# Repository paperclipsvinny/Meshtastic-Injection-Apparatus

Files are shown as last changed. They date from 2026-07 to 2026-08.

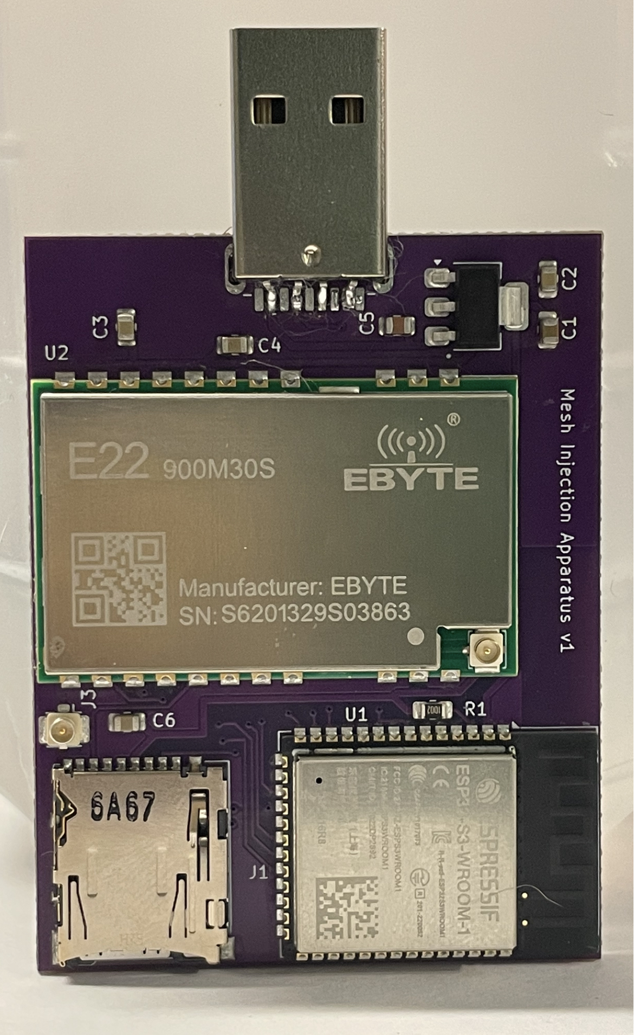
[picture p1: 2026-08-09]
website/assets/MIA-PCB-Front.jpg

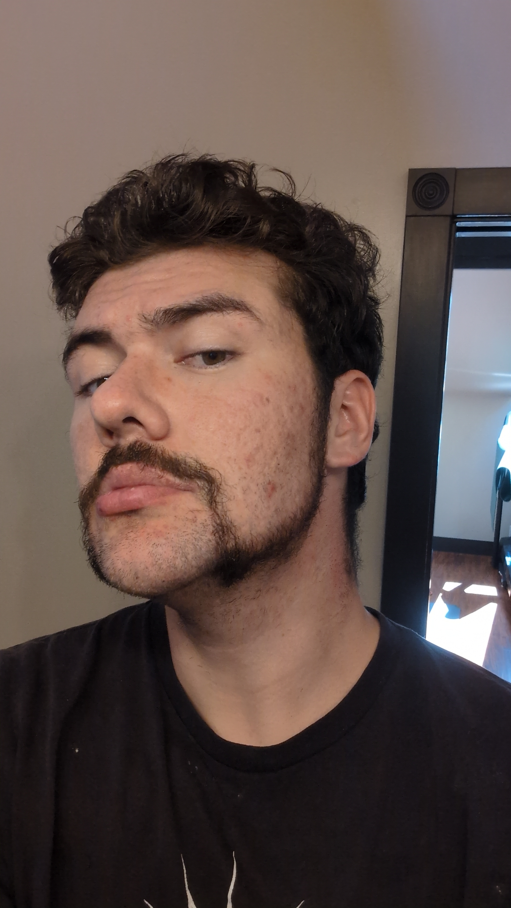
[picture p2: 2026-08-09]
photo1.jpg

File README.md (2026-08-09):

# Mesh Injection Apparatus (M.I.A.) 
A tool that combines HID injection with LoRa (Meshtastic) mesh networking for a red team implant that doesn't rely on WiFi or internet for C2. 
Board both sides

## DISCLAIMER: 
**This is a covert keystroke injection tool, designed for Red Teams, Penetration Testers, and authorized testing only. Do NOT use this tool on any systems which you have not been given express, explicit permission. I, the author, am not responsible for any damages which may incur from using this tool.** 

## Where is everything?
For Firmware Architecture notes, check out [ARCHITECTURE.md](./ARCHITECTURE.md). 
Hardware, Schematics and PCB manufacturing files can be found under [`/Hardware`](./Hardware) . 

For technical Documentation, head over to [DOCUMENTATION.md](docs/DOCUMENTATION.md), also available at [TheMIA.dev](https://themia.dev)

As debuted at the [DEF CON 34 Main stage](https://defcon.org/html/defcon-34/dc-34-speakers.html#content_66655)

## LICENSE: 
This project is released under the **MIT license**. 
 Anyone is permitted to modify, distribute, and use anything from this project for both private and commercial use. 
### Conditions: 
You must provide a copy of the original copyright notice and include the full MIT license text, found in LICENSE.txt. 
### Limitations: 
The software is NOT under any warranty, and the author will not be held responsible for any damages or issues arising from this software. The original Author’s name and original logos cannot be used for marketing or promotion. 

## Credits & Inspiration
- **[Meshtastic](https://meshtastic.org)** — the mesh protocol MIA builds on
- **[RadioLib](https://github.com/jgromes/RadioLib)** — LoRa radio abstraction
- **[Loki](https://github.com/RocketGod-git/Meshtastic-Loki)** — Meshtastic fork that added HID 
  support, the direct inspiration for MIA's development. 
- **[EvilCrowRF](https://github.com/joelsernamoreno/EvilCrowRF-V2)** — web dashboard 
  design inspiration.

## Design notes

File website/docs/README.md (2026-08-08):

# MIA Documentation

**M.esh I.njection A.pparatus** — wireless HID injection over encrypted LoRa mesh.

---

## Where to start

New here? Start with [Getting Started → Quickstart](getting-started/quickstart.md).

Already flashed? Jump to [Serial API](firmware/serial-api.md) or the [Web API](firmware/web-api.md).

Building hardware? See [Hardware Overview](hardware/overview.md).

---

## Contents

### Getting Started
- [Requirements](getting-started/requirements.md) — what you need before you begin
- [Flashing](getting-started/flashing.md) — web flasher + PlatformIO fallback
- [Quickstart](getting-started/quickstart.md) — fastest path to first injection

### Hardware
- [Overview](hardware/overview.md) — supported boards, pinouts
- [Bill of Materials](hardware/bill-of-materials.md) — what's on the MIA PCB
- [Heltec V3](hardware/heltec-v3.md) — reference platform notes
- [MIA PCB](hardware/mia-pcb.md) — custom board details

### Firmware
- [Architecture](firmware/architecture.md) — how the firmware is structured
- [Building](firmware/build.md) — PlatformIO setup and environments
- [Serial API](firmware/serial-api.md) — USB serial command reference
- [Web API](firmware/web-api.md) — HTTP endpoint reference
- [Payloads](firmware/payloads.md) — DuckyScript syntax and examples

### Meshtastic Integration
- [Overview](meshtastic-integration/overview.md) — how MIA fits into the mesh
- [Links](meshtastic-integration/links.md) — official Meshtastic resources

### Security
- [Considerations](security/considerations.md) — PSK handling, responsible use

### Contributing
- [Setup](contributing/setup.md) — dev environment
- [Code Style](contributing/code-style.md)
- [Changelog](contributing/changelog.md)

### [FAQ](faq.md)

---

Full docs are also available at **[themia.dev](https://themia.dev)**.

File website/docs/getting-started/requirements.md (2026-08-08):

# Requirements

## Hardware

You need one of these:

| Board | Notes |
|---|---|
| **Heltec WiFi LoRa 32 V3** | Reference platform. Tested and confirmed working. Has built-in display (unused by MIA), OLED, USB-C. |
| **MIA PCB v1** | Custom ESP32-S3 + E22-900M30S board. v2 in development. |

Any ESP32-S3 board with an SX1262-compatible LoRa module should work with minor pin changes — see [Building](../firmware/building.md).

You also need:
- A **USB data cable** (not charge-only — MIA enumerates as a USB keyboard)
- A **Meshtastic node** to send commands from — any standard device works (phone app, stock Heltec, T-Beam, etc.)
- An **antenna** for the LoRa module (900 MHz for US, 868 MHz for EU)

## Software

| Tool | Required for |
|---|---|
| Chrome or Edge | Web flasher at themia.dev |
| Python 3 + pyserial | Serial CLI (`tools/mia-cli.py`) |
| PlatformIO | Building from source |
| Meshtastic app | Sending commands over the mesh |

## OS support

MIA has been tested on **Linux** (Fedora, Ubuntu). It should work on macOS and Windows with the standard PlatformIO toolchain — serial port naming will differ (`/dev/cu.usbmodem*` on macOS, `COM*` on Windows).

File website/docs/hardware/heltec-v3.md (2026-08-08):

# Heltec WiFi LoRa 32 V3

The reference platform for MIA development. If you're just getting started, use this board.

## Specs

- **MCU:** ESP32-S3, 240MHz dual-core
- **Flash:** 8MB
- **LoRa:** SX1262, up to 22dBm TX power
- **USB:** Native USB-C (no separate UART bridge chip)
- **Display:** 0.96" OLED (unused by MIA firmware)
- **Buttons:** BOOT + RESET (makes flashing easy)

## Notes

- The Heltec V3 has a TCXO (temperature-compensated crystal oscillator) on the LoRa module at 1.8V — this is why `LORA_TXCOVOLT 1.8` is set in `Radio.h`. Don't remove this or the radio won't initialize.
- Native USB means the board enumerates as `/dev/ttyACM0` (not `/dev/ttyUSB0`) on Linux when using USB CDC mode. The `platformio.ini` `upload_port` should match whichever your system assigns.
- `ARDUINO_USB_CDC_ON_BOOT=0` is set for this board — serial output is available but the CDC interface doesn't start until after `Serial.begin()` in setup.
- `VEXT_ENABLE` (GPIO36, active LOW) controls power to peripherals including the display. MIA pulls this LOW on boot to enable the LoRa module's power path.

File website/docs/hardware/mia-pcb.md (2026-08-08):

# MIA PCB v1

A custom USB-A form-factor board designed to plug directly into a target machine and disappear — it looks like a USB drive.

## Design goals

- USB-A plug built into the PCB edge (gold-plated contacts) — plugs directly into any USB-A port
- ESP32-S3-WROOM-1 (N16R8) for processing and native USB HID
- E22-900M30S for long-range LoRa comms
- MicroSD slot for payload storage
- Compact enough to leave in a machine without drawing attention

## Current status

**v1 has a hardware bug** — A routing error on v1 boards prevents the E22 LoRa module from
initializing. v2 corrects the routing error and adds BOOT/RESET buttons + an LED.

## Pin mapping

| Signal | ESP32 GPIO |
|---|---|
| LORA_CS (NSS) | 8 |
| LORA_RST | 12 |
| LORA_BUSY | 13 |
| LORA_DIO1 | 14 |
| LORA_SCK | 9 |
| LORA_MOSI | 10 |
| LORA_MISO | 11 |
| SD_CS | 4 |
| SD_DETECT | 5 (optional) |
| USB_D- | 19 (native) |
| USB_D+ | 20 (native) |

## Flashing v1 boards

v1 has no BOOT/RESET buttons. To enter bootloader mode:
1. Bridge GPIO0 (physical pad 10 on the WROOM-1) to GND while powering on
2. Release after the board enumerates
3. Run `pio run -e mia_pcb -t upload`

Native USB auto-reset works once firmware is installed.

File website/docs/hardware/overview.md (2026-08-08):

# Hardware Overview

MIA firmware runs on ESP32-S3-based LoRa boards. The reference platform is the **Heltec WiFi LoRa 32 V3**.

## Supported boards

| Board | LoRa Module | Status |
|---|---|---|
| Heltec WiFi LoRa 32 V3 | SX1262 | ✅ Tested |
| MIA PCB v1 | E22-900M30S (SX1262-compatible) | 🔧 v2 in development |

## Pin mapping (Heltec V3 / MIA PCB v1)

| Signal | GPIO |
|---|---|
| LORA_CS | 8 |
| LORA_DIO1 | 14 |
| LORA_RST | 12 |
| LORA_BUSY | 13 |
| LORA_MISO | 11 |
| LORA_MOSI | 10 |
| LORA_SCK | 9 |

These are defined in `Radio.h` and can be changed per board via `#ifdef` guards in `platformio.ini`.

## Adding a new board

1. Add a new `[env:your_board]` in `platformio.ini`
2. Add `-DYOUR_BOARD` to `build_flags`
3. Add an `#ifdef YOUR_BOARD` pin block in `Radio.h`
4. Add `#ifndef YOUR_BOARD` guards around any board-specific peripherals in `main.cpp` (LED, VEXT, etc.)

See [Building](../firmware/building.md) for the full environment setup.

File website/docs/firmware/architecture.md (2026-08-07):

# Firmware Architecture

The firmware is divided into independent subsystems, each owning a single concern.

## Radio
- SPI/LoRa hardware initialization via RadioLib (SX1262/E22)
- Runtime-configurable parameters: frequency, bandwidth, spread factor, coding rate, TX power
- RX interrupt handling and packet reception
- Signal reporting: RSSI, SNR, IRQ flags
- NVS-backed persistence — settings survive reboot
- Getters/setters exposed to SerialApi and WebApi

## Crypto
- AES-CTR decryption using ESP32 hardware AES (mbedTLS)
- Supports AES-128 (16-byte) and AES-256 (32-byte) PSKs
- Per-packet nonce construction from packet ID + source address (Meshtastic CTR scheme)
- Runtime PSK update via setKey() — no reflash required
- NVS-backed persistence for active PSK

## PacketParser
- Parses the 14-byte Meshtastic packet header (dest, source, packetId, flags, channel)
- Extracts text messages from decrypted protobuf payloads (text app message format)
- Deduplication handled in main.cpp via packetId + source tracking

## HID
- DuckyScript command parsing and execution
- USB HID keyboard initialization and keystroke injection
- Handles modifier keys (CTRL, ALT, SHIFT, GUI) with press/release pairs
- Retransmission deduplication prevents duplicate command execution

## Logger
- Centralized serial output (raw, info, formatted, hex byte)
- Replaces all direct Serial.print calls throughout the firmware

## StatusLED
- Visual feedback via onboard LED
- 3x fast blink pattern on packet received
- Conditionally compiled out on boards with no LED (MIA_PCB)

## SerialApi
- JSON-over-serial command interface (115200 baud, newline-terminated)
- Commands: get_config, set_config, get_psk, set_psk, get_wifi, set_wifi,
  save_defaults, reset_defaults
- All changes applied live and persisted to NVS immediately

## WebApi
- HTTP server over ESP32 WiFi AP (ESPAsyncWebServer)
- Mirrors SerialApi's command surface over REST endpoints
- Serves web dashboard (index.html) from LittleFS
- WPA2-secured AP; POST endpoints require Content-Type: application/json

## WifiConfig
- Holds AP SSID, password, and enabled state
- NVS-backed persistence via Preferences
- Read/written by both SerialApi (set_wifi) and WebApi

## Multi-board support
Firmware supports multiple hardware targets via PlatformIO environments:
- `heltec_wifi_lora_32_V3` — Heltec WiFi LoRa 32 V3 (reference/tested platform)
- `mia_pcb` — MIA v1 custom PCB (ESP32-S3-WROOM-1 + E22-900M30S, pending hardware fix)

Board-specific differences (LED, VEXT_ENABLE) are handled via `#ifdef MIA_PCB` guards.

## Tools
- `tools/mia-cli.py` — interactive serial CLI (Python, `cmd` module)
  Commands: get/set/gen/defaults/monitor
  Connects over USB serial, no firmware changes required

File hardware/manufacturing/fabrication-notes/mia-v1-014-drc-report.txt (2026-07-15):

** Drc report for Mesh_Injection_Apparatus_v1_014.kicad_pcb **
** Created on 2026-07-10T18:35:10 **
** Report includes: Errors, Warnings **

** Found 7 DRC violations **
[copper_edge_clearance]: Board edge clearance violation (board setup constraints edge clearance 0.5000 mm; actual 0.0500 mm)
    Rule: board setup constraints edge; error
    @(137.5000 mm, 74.0000 mm): Polygon on Edge.Cuts
    @(156.0500 mm, 71.1500 mm): Pad 1 [+5V] of REF** on F.Cu
[copper_edge_clearance]: Board edge clearance violation (board setup constraints edge clearance 0.5000 mm; actual 0.1500 mm)
    Rule: board setup constraints edge; error
    @(137.5000 mm, 74.0000 mm): Polygon on Edge.Cuts
    @(158.5000 mm, 71.1500 mm): Pad 2 [Net-(J2-D-)] of REF** on F.Cu
[copper_edge_clearance]: Board edge clearance violation (board setup constraints edge clearance 0.5000 mm; actual 0.1500 mm)
    Rule: board setup constraints edge; error
    @(137.5000 mm, 74.0000 mm): Polygon on Edge.Cuts
    @(161.0000 mm, 71.1500 mm): Pad 3 [Net-(J2-D+)] of REF** on F.Cu
[copper_edge_clearance]: Board edge clearance violation (board setup constraints edge clearance 0.5000 mm; actual 0.1500 mm)
    Rule: board setup constraints edge; error
    @(137.5000 mm, 74.0000 mm): Polygon on Edge.Cuts
    @(163.5000 mm, 71.1500 mm): Pad 4 [GND] of REF** on F.Cu
[track_dangling]: Track has unconnected end
    Local override; warning
    @(150.7800 mm, 86.0000 mm): Track [Net-(U2-DIO2)] on B.Cu, length 2.5400 mm
[lib_footprint_issues]: The current configuration does not include the footprint library 'E22-900M30S'
    Local override; warning
    @(157.2600 mm, 97.5750 mm): Footprint U2
[lib_footprint_mismatch]: Footprint 'ESP32-S3-WROOM-1' does not match copy in library 'RF_Module'
    Local override; warning
    @(170.1487 mm, 123.2868 mm): Footprint U1

** Found 2 unconnected pads **
[unconnected_items]: Missing connection between items
    Local override; error
    @(148.2400 mm, 86.0000 mm): Pad 8 [Net-(U2-DIO2)] of U2 on F.Cu
    @(150.7800 mm, 86.0000 mm): Track [Net-(U2-DIO2)] on B.Cu, length 2.5400 mm
[unconnected_items]: Missing connection between items
    Local override; error
    @(150.7800 mm, 86.0000 mm): Track [Net-(U2-DIO2)] on B.Cu, length 2.5400 mm
    @(150.7800 mm, 86.0000 mm): Pad 7 [Net-(U2-DIO2)] of U2 on F.Cu

** Found 0 Footprint errors **

** Ignored checks **
    - Footprint has no courtyard defined
    - Track endpoint not centered on via
    - Tuning profile track geometries
    - Footprint doesn't match symbol's footprint filters
    - Footprint component type doesn't match footprint pads

** End of Report **

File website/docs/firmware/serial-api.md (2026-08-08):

# Serial API Reference

MIA accepts JSON commands over USB serial at **115,200 baud**. Each command is a single line of JSON terminated with a newline (`\n`).

The easiest way to interact with the serial API is the included CLI tool:

```bash
python3 tools/mia-cli.py /dev/ttyUSB0
```

Or raw serial (useful for scripting):

```bash
python3 -c "
import serial, time
s = serial.Serial('/dev/ttyUSB0', 115200, timeout=2)
time.sleep(5)          # wait for boot
s.reset_input_buffer()
s.write(b'{\"cmd\":\"get_config\"}\n')
time.sleep(0.5)
print(s.read(s.in_waiting or 1).decode())
"
```

> **Note:** Wait a few seconds after opening the port for the device to finish booting before sending commands. Sending too early can mix your command with boot output and cause a parse error.

---

## Radio configuration

### `get_config`

Returns current radio parameters.

**Request:**
```json
{"cmd": "get_config"}
```

**Response:**
```json
{
  "frequency": 906.875,
  "bandwidth": 250,
  "spreadFactor": 11,
  "codingRate": 5,
  "power": 22
}
```

---

### `set_config`

Updates one or more radio parameters. Only include the fields you want to change. Changes take effect immediately and persist across reboots.
- `frequency`: frequency in MHz (e.g. 906.875)
- `bandwidth`: bandwidth in kHz (e.g. 250.0)  
- `codingRate`: coding rate (5–8)
Example:
**Request:**
```json
{"cmd": "set_config", "spreadFactor": 9, "power": 17}
```

**Response:**
```json
{"status": "ok"}
```

**Valid ranges:**
- `spreadFactor`: 7–12 (RadioLib validates this; invalid values return `{"status":"error"}`)
- `power`: −9 to 22 dBm

---

## PSK (channel key)

### `get_psk`

Returns the current AES channel key as base64.

**Request:**
```json
{"cmd": "get_psk"}
```

**Response:**
```json
{"psk": "1PG7OiApB1nwvP+rz05pAQ=="}
```

The response includes the raw base64 key. Decode it to get the actual bytes: 24 characters = 16 bytes (AES-128), 44 characters = 32 bytes (AES-256).

---

### `set_psk`

Sets a new AES channel key. Must be a valid base64 string that decodes to exactly 16 bytes (AES-128) or 32 bytes (AES-256).

**Request:**
```json
{"cmd": "set_psk", "psk": "uUAKMhSSaaZpRNM0ytp6qw=="}
```

**Response:**
```json
{"status": "ok"}
```

To match a Meshtastic private channel, find the PSK in the Meshtastic app's channel settings (shown as base64) and pass it directly here.

---

## WiFi / AP settings

### `get_wifi`

Returns current WiFi AP configuration. The password is intentionally omitted from the response.

**Request:**
```json
{"cmd": "get_wifi"}
```

**Response:**
```json
{"enabled": true, "ssid": "Mesh Injection Apparatus"}
```

---

### `set_wifi`

Updates WiFi AP settings. Any combination of fields can be included. SSID and password changes require a reboot to take effect; the `enabled` toggle applies on the next boot.

**Request:**
```json
{"cmd": "set_wifi", "ssid": "MyMIA", "password": "newpassword", "enabled": true}
```

**Response:**
```json
{"status": "ok"}
```

---

## Defaults

### `save_defaults`

Saves the current configuration (radio, PSK, WiFi) as a named restore point. A subsequent `reset_defaults` will return to these values rather than the compiled-in factory values.

**Request:**
```json
{"cmd": "save_defaults"}
```

**Response:**
```json
{"status": "ok", "msg": "current config saved as defaults"}
```

---

### `reset_defaults`

Restores previously saved defaults. If no defaults have been saved, wipes NVS entirely and reverts to compiled-in factory values on next reboot.

**Request:**
```json
{"cmd": "reset_defaults"}
```

**Response:**
```json
{"status": "ok", "msg": "defaults restored, reboot to apply"}
```

or, if no saved defaults exist:

```json
{"status": "ok", "msg": "factory reset, reboot to apply"}
```

---

## Error responses

All commands return a consistent error format for invalid input:

| Response | Meaning |
|---|---|
| `{"error":"invalid json"}` | The line sent wasn't valid JSON |
| `{"error":"unknown cmd"}` | The `cmd` field wasn't recognized |
| `{"error":"psk must decode to 16 or 32 bytes"}` | The PSK base64 string decoded to an invalid length |
| `{"status":"error"}` | The radio rejected a parameter (e.g. out-of-range spread factor) |

---

## Serial CLI quick reference

```
mia> get config              read radio parameters
mia> get psk                 read current PSK
mia> get wifi                read AP settings
mia> get status              read everything at once

mia> set sf <7-12>           set spread factor
mia> set power <dBm>         set TX power
mia> set psk <base64>        set channel key
mia> set ssid <name>         set AP network name
mia> set password <pass>     set AP password
mia> set wifi <on|off>       enable or disable the AP

mia> set freq <MHz>          set frequency
mia> set bw <kHz>            set bandwidth  
mia> set cr <5-8>            set coding rate

mia> gen psk 128             generate and apply a random 128-bit key
mia> gen psk 256             generate and apply a random 256-bit key

mia> defaults save           save current config as restore point
mia> defaults reset          restore saved defaults (or factory reset)

mia> monitor                 stream live serial output
mia> exit                    disconnect
```

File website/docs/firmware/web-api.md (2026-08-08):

# Web API Reference

MIA exposes an HTTP REST API served over its own WiFi AP. All endpoints are available at `http://192.168.4.1` when connected to the MIA AP.

> **Important:** POST endpoints require the header `Content-Type: application/json`. Omitting this header causes ESPAsyncWebServer to skip the request body, resulting in a silent empty response.

---

## Radio configuration

### `GET /api/config`

Returns current radio parameters.

**Response:**
```json
{
  "frequency": 906.875,
  "bandwidth": 250,
  "spreadFactor": 11,
  "codingRate": 5,
  "power": 22
}
```

---

### `POST /api/config`

Updates radio parameters. Only include fields you want to change.

**Request:**
```json
{"spreadFactor": 9, "power": 17}
```

**Response:**
```json
{"status": "ok"}
```

**Example:**
```bash
curl -X POST http://192.168.4.1/api/config \
  -H "Content-Type: application/json" \
  -d '{"spreadFactor": 9}'
```

---

## PSK (channel key)

### `GET /api/psk`

Returns the current AES key as base64.

**Response:**
```json
{"psk": "1PG7OiApB1nwvP+rz05pAQ=="}
```

---

### `POST /api/psk`

Sets a new AES channel key.

**Request:**
```json
{"psk": "uUAKMhSSaaZpRNM0ytp6qw=="}
```

Must decode to exactly 16 bytes (AES-128) or 32 bytes (AES-256).

---

## WiFi / AP settings

### `GET /api/wifi`

Returns current AP configuration. Password is omitted.

**Response:**
```json
{"enabled": true, "ssid": "Mesh Injection Apparatus"}
```

---

### `POST /api/wifi`

Updates AP settings. Include any combination of fields.

**Request:**
```json
{"enabled": true, "ssid": "MyMIA", "password": "newpassword"}
```

SSID and password take effect after reboot.

---

## Inject

### `POST /api/inject/fire`

Executes a DuckyScript command locally via USB HID. The MIA device must be plugged into a target machine.

**Request:**
```json
{"command": "STRINGLN hello world"}
```

The `!mia:` prefix is stripped automatically if present.

**Response:**
```json
{"status": "ok"}
```

**Example:**
```bash
curl -X POST http://192.168.4.1/api/inject/fire \
  -H "Content-Type: application/json" \
  -d '{"command": "GUI r, DELAY 500, STRINGLN notepad, ENTER"}'
```

---

### `POST /api/inject/transmit`

Transmits a `!mia:` prefixed command over LoRa to other MIA devices on the same channel.

**Request:**
```json
{"command": "STRINGLN hello from MIA"}
```

**Response:**
```json
{"status": "ok"}
```

---

### `GET /api/inject/payloads`

Lists payload files stored on the device filesystem.

**Response:**
```json
[
  {"name": "open_terminal.txt", "size": 42},
  {"name": "reverse_shell.txt", "size": 128}
]
```

---

### `POST /api/inject/upload`

Uploads a DuckyScript payload file to the device. Uses multipart form upload.

**Example:**
```bash
curl -X POST http://192.168.4.1/api/inject/upload \
  -F "file=@payload.txt"
```

---

### `DELETE /api/inject/payload`

Deletes a stored payload by name.

**Request:**
```json
{"name": "open_terminal.txt"}
```

---

## Board info

### `GET /api/board`

Returns device information.

**Response:**
```json
{
  "version": "0.9.0",
  "mac": "3C:0F:02:ED:BF:8C",
  "uptime": 123456,
  "freeHeap": 245760
}
```

`uptime` is in milliseconds since last boot.

---

## Defaults

### `POST /api/defaults`

Saves or resets device configuration.

**Save current config as defaults:**
```json
{"action": "save"}
```

**Reset to saved defaults (or factory values):**
```json
{"action": "reset"}
```

---

## Reboot

### `POST /api/reboot`

Reboots the device. The connection will drop immediately after the response.

**Request:** empty body or `{}`

**Response:**
```json
{"status": "ok"}
```

---

## Static files

The web dashboard (`index.html`, `logo.png`) is served from LittleFS at the root path. Any file placed in `firmware/data/` and uploaded via `pio run -t uploadfs` will be accessible at `http://192.168.4.1/<filename>`.

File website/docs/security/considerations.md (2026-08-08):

# Security Considerations

## PSK handling

MIA stores its channel PSK in NVS (ESP32 non-volatile storage). This is flash memory on the device itself — not transmitted anywhere, not stored in plaintext in any file that gets committed to git.

The PSK is exposed over:
- **Serial CLI** via `get psk` — requires physical USB access to the device
- **Web dashboard** via `GET /api/psk` — requires connecting to the MIA WiFi AP

The WiFi AP is WPA2-protected. Anyone who doesn't know the AP password cannot reach the PSK endpoint. The PSK is transmitted in transit as base64 JSON over HTTP — which is plaintext at the HTTP layer, but already encrypted at the WiFi (WPA2) layer. This is an acceptable trust boundary for a local AP.

## AP security model

The MIA AP is WPA2-secured with a configurable password. The default password (`Mesh-Inject-7f3K9pQ2`) should be changed before operational deployment:

```
mia> set password <your-strong-password>
```

Anyone who connects to the AP has full access to the web dashboard and all API endpoints, including the ability to change the PSK, fire HID commands, and reboot the device. Treat AP access as equivalent to physical access.

## Channel security

The `!mia:` prefix is not authenticated beyond the shared channel PSK. Anyone who knows the channel key and is on the same Meshtastic frequency can send commands to a MIA device. This is intentional for the multi-operator use case but means the channel PSK is your primary access control mechanism.

Use a private channel with a strong, randomly generated PSK for any non-public deployment:

```
mia> gen psk 256
```

## Responsible use

MIA is a security research and education tool. Use it only on systems and networks you own or have explicit written permission to test. Unauthorized HID injection is illegal in most jurisdictions.

The author is not responsible for misuse.

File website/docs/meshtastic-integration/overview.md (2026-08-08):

# Meshtastic Integration

MIA is built on top of the Meshtastic protocol. It doesn't modify Meshtastic — it implements a compatible receive/decrypt path so it can listen to a standard mesh and act on specific messages.

## How it fits in

```
[Any Meshtastic node]
        |
        | LoRa (encrypted, AES-128 or AES-256)
        |
[MIA device]
        |
        | USB HID
        |
[Target machine]
```

The operator can be anything that sends Meshtastic messages: the official app on Android/iOS, a stock Heltec, a T-Beam, a T-Deck, another MIA device. MIA only cares about receiving.

## Channels and PSKs

Meshtastic organizes communication into channels, each with its own PSK (pre-shared key). MIA listens on whichever channel its PSK is configured for.

The default PSK (`1PG7OiApB1nwvP+rz05pAQ==`) matches Meshtastic's public **LONGFAST** channel — the default channel all Meshtastic devices use out of the box.

To operate on a private channel:
1. Create a private channel in the Meshtastic app
2. Copy the channel's PSK (shown as base64 in channel settings)
3. Set it on MIA via `set psk <base64>` in the serial CLI or **Settings → Key** in the web dashboard

## The `!mia:` prefix

MIA filters messages by the `!mia:` prefix. Any text message on the configured channel that starts with `!mia:` is treated as a command. Everything after the prefix is passed to the DuckyScript parser.

This means:
- Regular mesh traffic is ignored
- Commands are explicit and intentional
- Multiple MIA devices on the same channel all respond to the same commands (broadcast by design — useful for multi-implant scenarios)

## Retransmission and deduplication

Meshtastic automatically retransmits messages when it doesn't receive delivery confirmation. This is normal behavior but would cause MIA to execute the same command multiple times.

MIA deduplicates by tracking the last executed packet ID and source address. If the same packet arrives again (same ID + same source), it's logged and skipped.

## Radio parameters

MIA ships configured for LONGFAST:

| Parameter | Value |
|---|---|
| Frequency | 906.875 MHz (US) |
| Bandwidth | 250 kHz |
| Spread Factor | 11 |
| Coding Rate | 5 |
| Sync Word | 0x2B |

These can be changed at runtime via the serial CLI or web dashboard. Both MIA and the sending node must use matching parameters to communicate.

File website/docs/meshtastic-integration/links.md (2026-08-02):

# Meshtastic Resources

The MIA builds on top of the Meshtastic protocol and radio parameters (LONGFAST
preset, channel PSKs, packet structure). For anything not specific to MIA
itself, refer to the official docs:

- **Getting started / device setup**: https://meshtastic.org/docs/getting-started/
- **Full documentation**: https://meshtastic.org/docs/
- **Protocol / packet structure**: https://meshtastic.org/docs/overview/mesh-algo/
- **Channels & PSKs**: https://meshtastic.org/docs/configuration/radio/channels/
- **Python API** (useful for testing/tooling against MIA): https://python.meshtastic.org/

MIA intentionally does not modify or extend the Meshtastic protocol — it implements a
compatible receive/decrypt path so it can interoperate with a standard mesh.

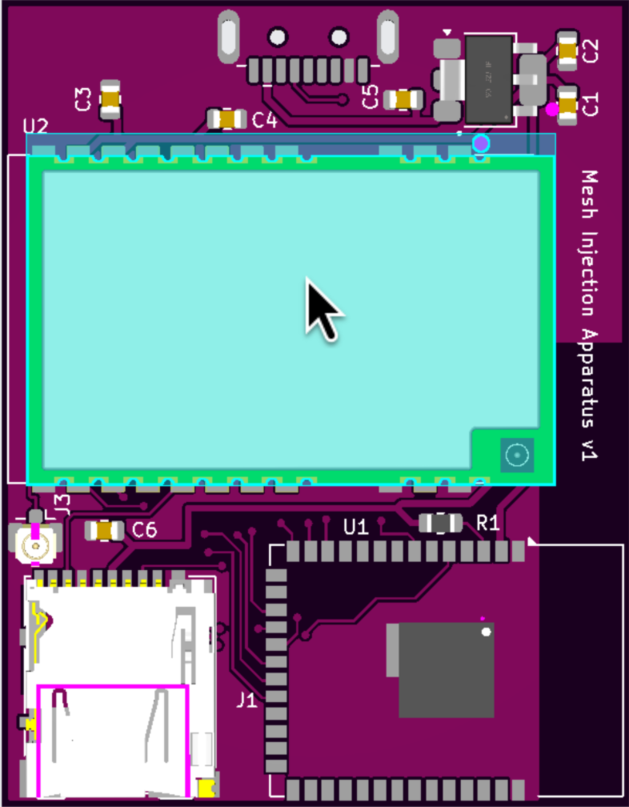
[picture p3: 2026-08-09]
website/assets/PCBrender.png

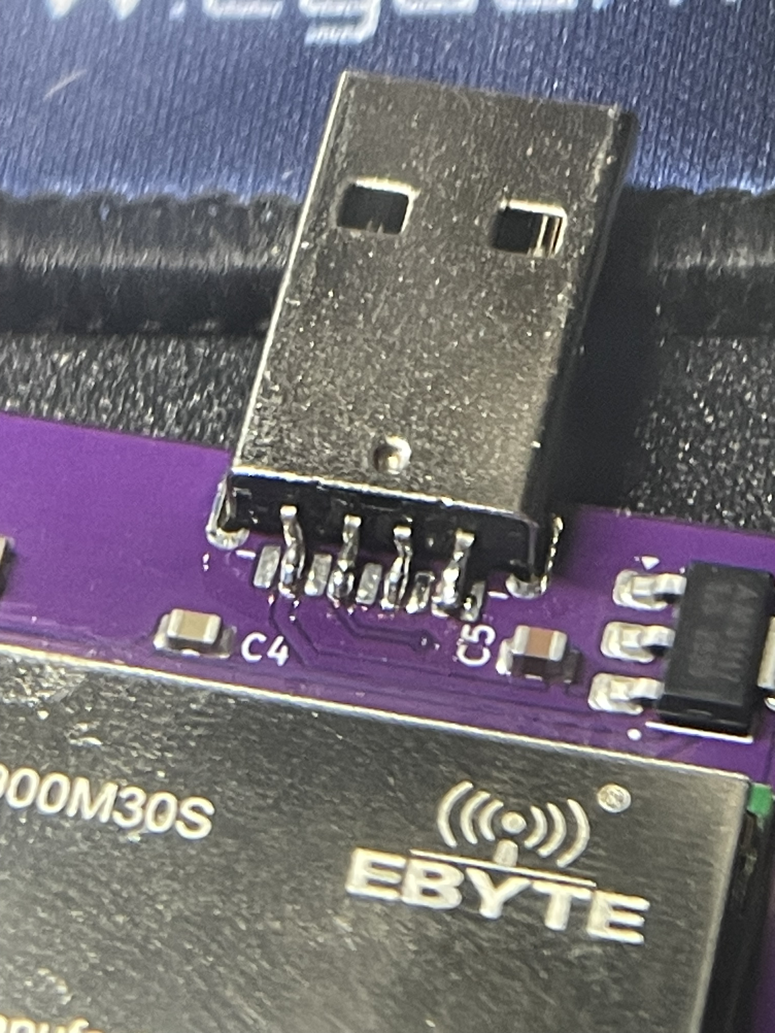
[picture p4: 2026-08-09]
website/assets/MIA-Close-Up.jpeg

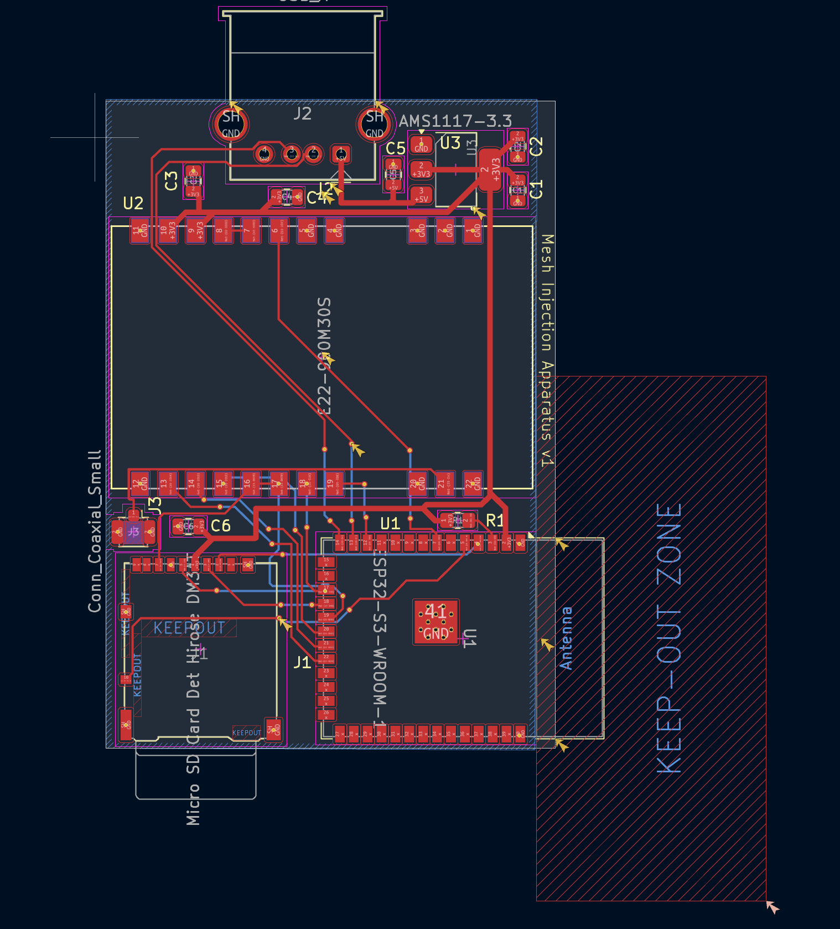
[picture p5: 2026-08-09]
website/assets/PCBInternal.png

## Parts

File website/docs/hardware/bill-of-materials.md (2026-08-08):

# Bill of Materials — MIA PCB v1

Custom USB-A form-factor board designed to plug directly into a target machine.

| Ref | Component | Value | Notes |
|---|---|---|---|
| U1 | ESP32-S3-WROOM-1 | N16R8 | 16MB flash, 8MB PSRAM |
| U2 | E22-900M30S | — | SX1262-based, 30dBm, 900MHz |
| U3 | AMS1117-3.3 | 3.3V LDO | Powers ESP32 + E22 + SD |
| J1 | Hirose DM3AT | MicroSD slot | SPI mode |
| J2 | USB-A connector | PCB edge | Gold-plated castellated contacts |
| C1 | 10µF | VBUS bypass | |
| C2 | 10µF | 3.3V output bypass | |
| C3 | 22µF | 3.3V bulk | |
| C4 | 100nF | ESP32 decoupling | |
| C5 | 100nF | EN pin bypass | |
| C6 | 100nF | E22 decoupling | |
| C7 | 100nF | SD card decoupling | |
| R1 | 10kΩ | EN pull-up | |

## Known issues (v1)

- MOSI and MISO pads on U2 (E22) are shorted on the PCB — radio does not initialize. v2 corrects this routing error.
- No BOOT or RESET buttons — bootloader entry requires bridging GPIO0 to GND manually.

## v2 planned fixes

- Correct MOSI/MISO routing
- Add BOOT + RESET tactile buttons
- Verify all E22 control pin connections end-to-end before fab

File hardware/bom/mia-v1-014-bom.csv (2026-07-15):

Id | Designator | Footprint | Quantity | Designation | Supplier and ref
1 | C1 | C_0805_2012Metric | 1 | 22μF
2 | C2, C3, C4, C6 | C_0805_2012Metric | 4 | 100nF
3 | C5 | C_0805_2012Metric | 1 | 10μF
4 | J1 | microSD_HC_Hirose_DM3AT-SF-PEJM5 | 1 | Micro SD Card Det Hirose DM3AT
5 | J2 | USB3_A_Plug_Wuerth_692112030100_Horizontal | 1 | USB_A
6 | J3 | U.FL_Hirose_U.FL-R-SMT-1_Vertical | 1 | Conn_Coaxial_Small
7 | R1 | R_0805_2012Metric_Pad1.20x1.40mm_HandSolder | 1 | 10k
8 | U1 | ESP32-S3-WROOM-1 | 1 | ESP32-S3-WROOM-1
9 | U2 | XCVR_E22-900M30S | 1 | E22-900M30S
10 | U3 | SOT-223-3_TabPin2 | 1 | AMS1117-3.3

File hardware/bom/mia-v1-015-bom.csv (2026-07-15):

Id | Designator | Footprint | Quantity | Designation | Supplier and ref
1 | C1 | C_0805_2012Metric | 1 | 22μF
2 | C2, C3, C4, C6 | C_0805_2012Metric | 4 | 100nF
3 | C5 | C_0805_2012Metric | 1 | 10μF
4 | J1 | microSD_HC_Hirose_DM3AT-SF-PEJM5 | 1 | Micro SD Card Det Hirose DM3AT
5 | J3 | U.FL_Hirose_U.FL-R-SMT-1_Vertical | 1 | Conn_Coaxial_Small
6 | R1 | R_0805_2012Metric_Pad1.20x1.40mm_HandSolder | 1 | 10k
7 | REF** | USB_A_Male_GoldFinger | 1 | USB_A_Male_GoldFinger
8 | U1 | ESP32-S3-WROOM-1 | 1 | ESP32-S3-WROOM-1
9 | U2 | XCVR_E22-900M30S | 1 | E22-900M30S
10 | U3 | SOT-223-3_TabPin2 | 1 | AMS1117-3.3

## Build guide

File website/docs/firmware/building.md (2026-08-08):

# Building from Source

## Prerequisites

- [PlatformIO Core](https://docs.platformio.org/en/latest/core/installation/index.html) or the PlatformIO IDE extension for VS Code
- Python 3 (for the serial CLI tool)
- Git

## Clone and build

```bash
git clone https://github.com/paperclipsvinny/Meshtastic-Injection-Apparatus
cd Meshtastic-Injection-Apparatus/firmware

# build (compiles all environments)
pio run

# build a specific environment
pio run -e heltec_wifi_lora_32_V3
pio run -e mia_pcb
```

## Flash

```bash
# flash firmware to Heltec V3
pio run -e heltec_wifi_lora_32_V3 -t upload

# flash web dashboard to device filesystem (required separately)
pio run -e heltec_wifi_lora_32_V3 -t uploadfs
```

Always run both commands when setting up a new device. Firmware and filesystem are separate flash operations.

## Environments

| Environment | Board | Upload port |
|---|---|---|
| `heltec_wifi_lora_32_V3` | Heltec WiFi LoRa 32 V3 | `/dev/ttyUSB0` |
| `mia_pcb` | MIA PCB v1 (ESP32-S3-WROOM-1) | `/dev/ttyACM0` |

Ports are set in `platformio.ini` — update `upload_port` to match your system if needed.

## Key build flags

| Flag | Environment | Effect |
|---|---|---|
| `-DMIA_PCB` | `mia_pcb` | Disables LED, VEXT_ENABLE; selects MIA PCB pin defs |
| `-DARDUINO_USB_MODE=1` | both | Enables native USB mode |
| `-DARDUINO_USB_CDC_ON_BOOT=0` | Heltec | CDC serial starts after `Serial.begin()` |
| `-DARDUINO_USB_CDC_ON_BOOT=1` | MIA PCB | CDC serial available from boot |

## Dependencies

All managed by PlatformIO automatically:

- `jgromes/RadioLib` — LoRa radio abstraction
- `bblanchon/ArduinoJson@^7.0.0` — JSON parsing for serial/web API
- `esphome/ESPAsyncWebServer-esphome@^3.0.0` — async HTTP server

## Filesystem

Web dashboard files live in `firmware/data/`. Upload them to the device:

```bash
pio run -e heltec_wifi_lora_32_V3 -t uploadfs
```

Note: This is separate from the firmware flash and uses LittleFS. Both must be done for the web dashboard to work.

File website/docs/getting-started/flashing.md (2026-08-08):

# Flashing

## Option A: Web flasher (recommended)

Visit **[themia.dev/flash](https://themia.dev/flash)** in Chrome or Edge.

1. Plug in your device via USB
2. Select your board from the dropdown
3. Click **Flash**
4. Wait ~30 seconds for the firmware and filesystem to write
5. The device reboots automatically when done

No software installation required. Chrome or Edge only — Web Serial API isn't supported in Firefox or Safari.

## Option B: PlatformIO

For building from source or flashing a custom build:

```bash
git clone https://github.com/paperclipsvinny/Meshtastic-Injection-Apparatus
cd Meshtastic-Injection-Apparatus/firmware

# install dependencies (first time only)
pio pkg install

# flash firmware
pio run -e heltec_wifi_lora_32_V3 -t upload

# flash web dashboard to device filesystem (required)
pio run -e heltec_wifi_lora_32_V3 -t uploadfs
```

Both commands are required. `-t upload` writes the firmware binary; `-t uploadfs` writes the web dashboard files to LittleFS. Missing the second step results in a blank page at `http://192.168.4.1`.

## Option C: esptool directly

If you have pre-built binaries:

```bash
esptool.py --chip esp32s3 --port /dev/ttyACM0 --baud 460800 write_flash \
  0x0      bootloader.bin \
  0x8000   partitions.bin \
  0xe000   boot_app0.bin \
  0x10000  firmware.bin
```

## Entering bootloader mode

Most ESP32-S3 boards with native USB auto-reset into download mode when esptool connects — no button press needed.

If it fails to connect, manually enter bootloader mode:
1. Hold the **BOOT** button (or bridge GPIO0 to GND on boards without a button)
2. Press and release **RESET** (or briefly bridge EN to GND)
3. Release BOOT
4. Run the flash command

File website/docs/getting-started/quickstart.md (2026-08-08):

# Quickstart

Five (ish) minutes from unboxing to your first injection.

## 1. Flash

Visit **[themia.dev/flash](https://themia.dev/flash)**, plug in your device, click Flash.

## 2. Connect to the dashboard (optional)

After booting, connect to the MIA WiFi AP if you want to control it over the ESP32's WiFi portal:

- **SSID:** `Mesh Injection Apparatus`
- **Password:** `Mesh-Inject-7f3K9pQ2`

Open **http://192.168.4.1** in your connected device's browser. From here you can change radio and crypto settings as well as upload payloads, and more. 

This is completely optional, (but useful if you don't have a second Meshtastic node handy to send commands from) and it can be disabled via settings (see firmware for more details). 

## 3. Plug into a target

Plug the MIA device into the machine you want to inject keystrokes into. It shows up as a USB keyboard — no driver install needed.

## 4. Send a command

From the **Meshtastic app** on any node on the same channel, send:

```
!mia: STRINGLN hello world
```

The target machine types `hello world` and presses Enter.

That's it. Everything else — private channels, custom payloads, radio settings — is optional from here.

---

## What just happened

Your Meshtastic node transmitted that message over LoRa. MIA received it, saw the `!mia:` prefix, decrypted the payload using the shared channel key, and passed the DuckyScript command to the USB HID stack, which typed it on the target.

The whole chain is encrypted in transit using AES (128-bit by default on the public LONGFAST channel). Switch to a private channel with a custom PSK "to keep your OPSEC clean".

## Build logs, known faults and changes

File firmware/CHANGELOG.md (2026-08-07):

# Changelog

All notable changes to MIA will be documented in this file.

## [v0.8.0]
- Added web dashboard (index.html served from LittleFS over WiFi AP) —
  radio config, PSK, WiFi settings, saved payloads, serial monitor, board info
- Added mia-cli.py — Metasploit-style serial CLI with get/set/gen/defaults/monitor
- Added LittleFS filesystem support to both board environments
- Added save_defaults/reset_defaults commands (serial + web)
- Added factory reset with user-defined restore point

## [v0.7.1]
- Added NVS-backed persistence (Preferences library) for Radio config
  (frequency, bandwidth, spread factor, coding rate, power), Crypto's
  PSK, and WifiConfig (ssid, password, enabled).
- All three load stored values on boot, falling back to compiled-in
  defaults if nothing has been saved yet; every setter writes through
  to flash immediately.
- Verified via physical power cycle: spread factor, PSK, and SSID
  changes all survive a full unplug/replug.

## [v0.7.0]
- Extended Crypto to support both 128-bit (AES-128) and 256-bit (AES-256)
  PSKs, matching Meshtastic's private channel key lengths.
- Added get_psk/set_psk to SerialApi and WebApi — PSK read/write as
  base64, mirroring the existing config command pattern.
- Verified end-to-end: created 128-bit and 256-bit private channels in
  the Meshtastic app, confirmed MIA correctly decrypts real text messages
  and dispatches !mia: commands on both.

Note: MIA tracks a single active PSK at a time — switching channels
requires re-sending set_psk with the new channel's key. Persistence for
Radio config, WifiConfig, and PSK is still pending (separate step).

## [v0.6.1]
- Extracted packet header parsing and text-message extraction from main.cpp's
  loop() into a new PacketParser module (PacketParser.h/.cpp), in order to 
  cleanly prepare for private channel & custom PSK support (not broadcast).
- PacketHeader struct groups dest/source/packetId/flags/channel.
- extractTextMessage() now also returns the protobuf-reported text length
  via an out-parameter, restoring the "Text length = N" log line.

## [v0.6.0]
- Added `WebApi` module — HTTP interface mirroring SerialApi's get_config/
  set_config commands, served over the ESP32's own WiFi AP.
- Added `WifiConfig` (`WifiConfig.h`) — holds AP SSID, password, and enabled
  state. Not yet persisted; resets to defaults on reboot.
- Extended `SerialApi` with `get_wifi` / `set_wifi` for reading and toggling
  AP settings over serial.
**Endpoints:**
- `GET /api/config` — returns frequency, bandwidth, spread factor, coding
  rate, power
- `POST /api/config` — accepts spread factor and/or power; requires
  `Content-Type: application/json`

Note: `apEnabled` is temporarily defaulted to `true` in `WifiConfig.h` since
live-start and persistence aren't implemented yet — both planned for the
next release. AP currently broadcasts on every boot using the default
SSID/password.

## [v0.5.0]
- Added `SerialApi` module (`SerialApi.h` / `SerialApi.cpp`) — JSON-based command
  interface over USB serial for reading and modifying radio config at runtime.
- Added bblanchon's ArduinoJson library to Plaform.ini's dependancies. 
- Added `DOCUMENTATION.md` in `/docs` in order to note format for changing radio variables.
- Added `MESHTASTIC-RESOURCES.md` to make a place for all Meshtastic Links and documentation.

## [v0.4.0]
-Moving towards changing radio variables over Serial (and eventually web).
- Convert Radio class from static to instance-based methods, enabling runtime-editable radio config (spread factor, power)
- Add getters/setters for radio frequency, bandwidth, spread factor, coding rate, and power
- Rename internal SX1262 driver object to objectSX1262 to avoid naming collision with the new Radio instance 

## [v0.3.3]
-Introduced `StatusLED` module (`Status.LED` class), which is responsible for the status LED blink.
-Notes: Currently hardcoded to blink three times on recieve.

## [v0.3.2]
-Introduced `Crypto` module (`Crypto.h` / `Crypto.cpp`) as the logic responsible for AES-CTR decryption. 
**Crypto is now responsible for:**
- Initializing the AES engine with a 128-bit key (`Crypto::begin(key)`)
- Constructing the per-packet nonce from packet ID + source address, per Meshtastic's
  CTR-mode scheme (`Crypto::buildNonce`, private)
- Decrypting a packet's payload given its ciphertext, length, packet ID, and source
  address (`Crypto::decrypt`)

Note that the key value is still stored in Main. 

## [v0.3.1]
### Added
- Introduced `Radio` module (`Radio.h` / `Radio.cpp`) as the dedicated interface for SX1262 radio communication.
- Added a public hardware abstraction layer for:
  - Radio initialization
  - Packet reception
  - Receive interrupt handling
  - RSSI retrieval
  - SNR retrieval
  - IRQ flag access

### Changed
- Moved all LoRa hardware configuration, SPI initialization, and RadioLib setup out of `main.cpp`.
- Replaced direct `radio` object access throughout the application with calls to the `Radio` interface.
- Centralized LoRa configuration constants inside the radio module.

### Internal
- Reduced responsibility of `main.cpp`; it now coordinates application flow instead of managing radio hardware directly.
- Continued migration toward a modular firmware architecture in preparation for additional subsystem extraction.

##[v0.2.0]
### Added
- `Logger` class (`firmware/include/Logger.h`, `firmware/src/Logger.cpp`) — centralizes all serial output, replacing direct `Serial.print`/`println`/`printf` calls throughout `main.cpp`. No functional/output change; groundwork for future web-based logging.
- `Version.h` with firmware version constant, printed on boot.
- `HID` class (`firmware/include/HID.h`, `firmware/src/HID.cpp`) — extracts DuckyScript command parsing and USB keyboard execution from `main.cpp` into its own module, following the same pattern as `Logger`. No functional change beyond the fixes listed below.

### Fixed
- `Logger::raw(float)` was using the wrong format specifier (`%d` instead of `%f`), causing RSSI/SNR values to print as garbage (`-2147483648`) instead of correct decimal readings.
- `upload_port` in `platformio.ini` was hardcoded to a Windows-style COM port; corrected for Linux (`/dev/ttyUSB0`).
- `Keyboard.write()` was used alongside `Keyboard.press(modifier)` for CTRL/ALT/SHIFT/GUI combos, which caused the modifier key to remain logically "stuck" held after the command completed — `write()`'s internal key-translation interfered with the already-held modifier's state. Replaced `write()` with explicit `press()`+`release()` pairs for the combo'd key across all four modifier handlers, and added a `Keyboard.releaseAll()` safety-net call at the end of every command as insurance against future stuck-key regressions. Confirmed fixed via live testing (CTRL+T no longer sticks, opens a proper new tab).
- Meshtastic automatically retransmits a message when it doesn't receive delivery confirmation (common with only two nodes on the mesh) — this caused the same command to be re-executed multiple times. Added packet ID + source deduplication in the receive path to skip re-execution of retransmitted copies of an already-handled command. Confirmed fixed via live testing (single execution per logical command, duplicates correctly logged and skipped).

### Changed
- Repository restructured into monorepo layout: `firmware/`, `hardware/`, `website/`, `docs/`, `examples/`. See tag `v0.2.0-restructure`.

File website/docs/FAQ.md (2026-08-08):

# FAQ

**Do I need two MIA devices?**

No. You need one MIA device (the implant, plugged into the target) and any standard Meshtastic node to send commands. The operator side can be the official Meshtastic app on a phone, a stock Heltec, T-Beam, really anything that can send text messages on the same channel.

**Can I use this for "red team engagements"?**

MIA is a research tool. Use it only on systems you own or have explicit written permission to test. I'm not repsonsible for your actions! 

**Why does it say `Radio init failed`?**

The most common cause is a hardware issue — loose LoRa module, bad solder joint, or a pin mismatch between the firmware and the board. A good starting point is to check the [Hardware Overview](hardware/overview.md) and verify your pin definitions match the actual board wiring, as well as check physical connections with a multimeter.

**Why is the web dashboard a blank page?**
Well, assuming the MIA dashboard doesn't throw an error but rather just shows as blank, the issue is likely that you ran `pio run -t upload` but forgot `pio run -t uploadfs`. Both are required — firmware and filesystem are separate. Run `uploadfs` and try again. 

**Can MIA receive and execute commands at the same time?**

Yes. MIA is always in receive mode unless it's actively transmitting (TX then immediately returns to RX). The USB HID execution happens inline when a matching packet arrives.

**What happens if the same HID command arrives twice (commands relayed by other nodes)?**

MIA deduplicates by packet ID and source address. Meshtastic retransmits unacknowledged packets automatically — MIA detects and skips these duplicates so each command executes exactly once.

**Can I change the channel frequency?**

Both MIA and the sending node must use matching radio parameters. 
See [Meshtastic channel configuration](https://meshtastic.org/docs/configuration/radio/channels/) 
for how to set matching parameters on your sending node, and 
[Radio Settings](../firmware/serial-api.md#radio-configuration) for how to 
configure MIA's side.

**Does this work outside the US?**

The default frequency (906.875 MHz) is the US LONGFAST channel. For EU operation you'd need to change the frequency to 868.0 MHz and match Meshtastic's EU LONGFAST parameters. Check local regulations for LoRa frequency usage.

**Is the PSK stored securely?**

The PSK is stored in ESP32 NVS (flash). It's not transmitted over the air by the device, and it's not in any file that gets committed to git. Access requires either physical USB access or knowing the WiFi AP password. See [Security Considerations](security/considerations.md).

**What DuckyScript commands are supported?**

STRING, STRINGLN, ENTER, DELAY, GUI, CTRL, ALT, SHIFT, TAB, ESCAPE, BACKSPACE, and arrow keys. See [Payloads](firmware/payloads.md) for the full reference.

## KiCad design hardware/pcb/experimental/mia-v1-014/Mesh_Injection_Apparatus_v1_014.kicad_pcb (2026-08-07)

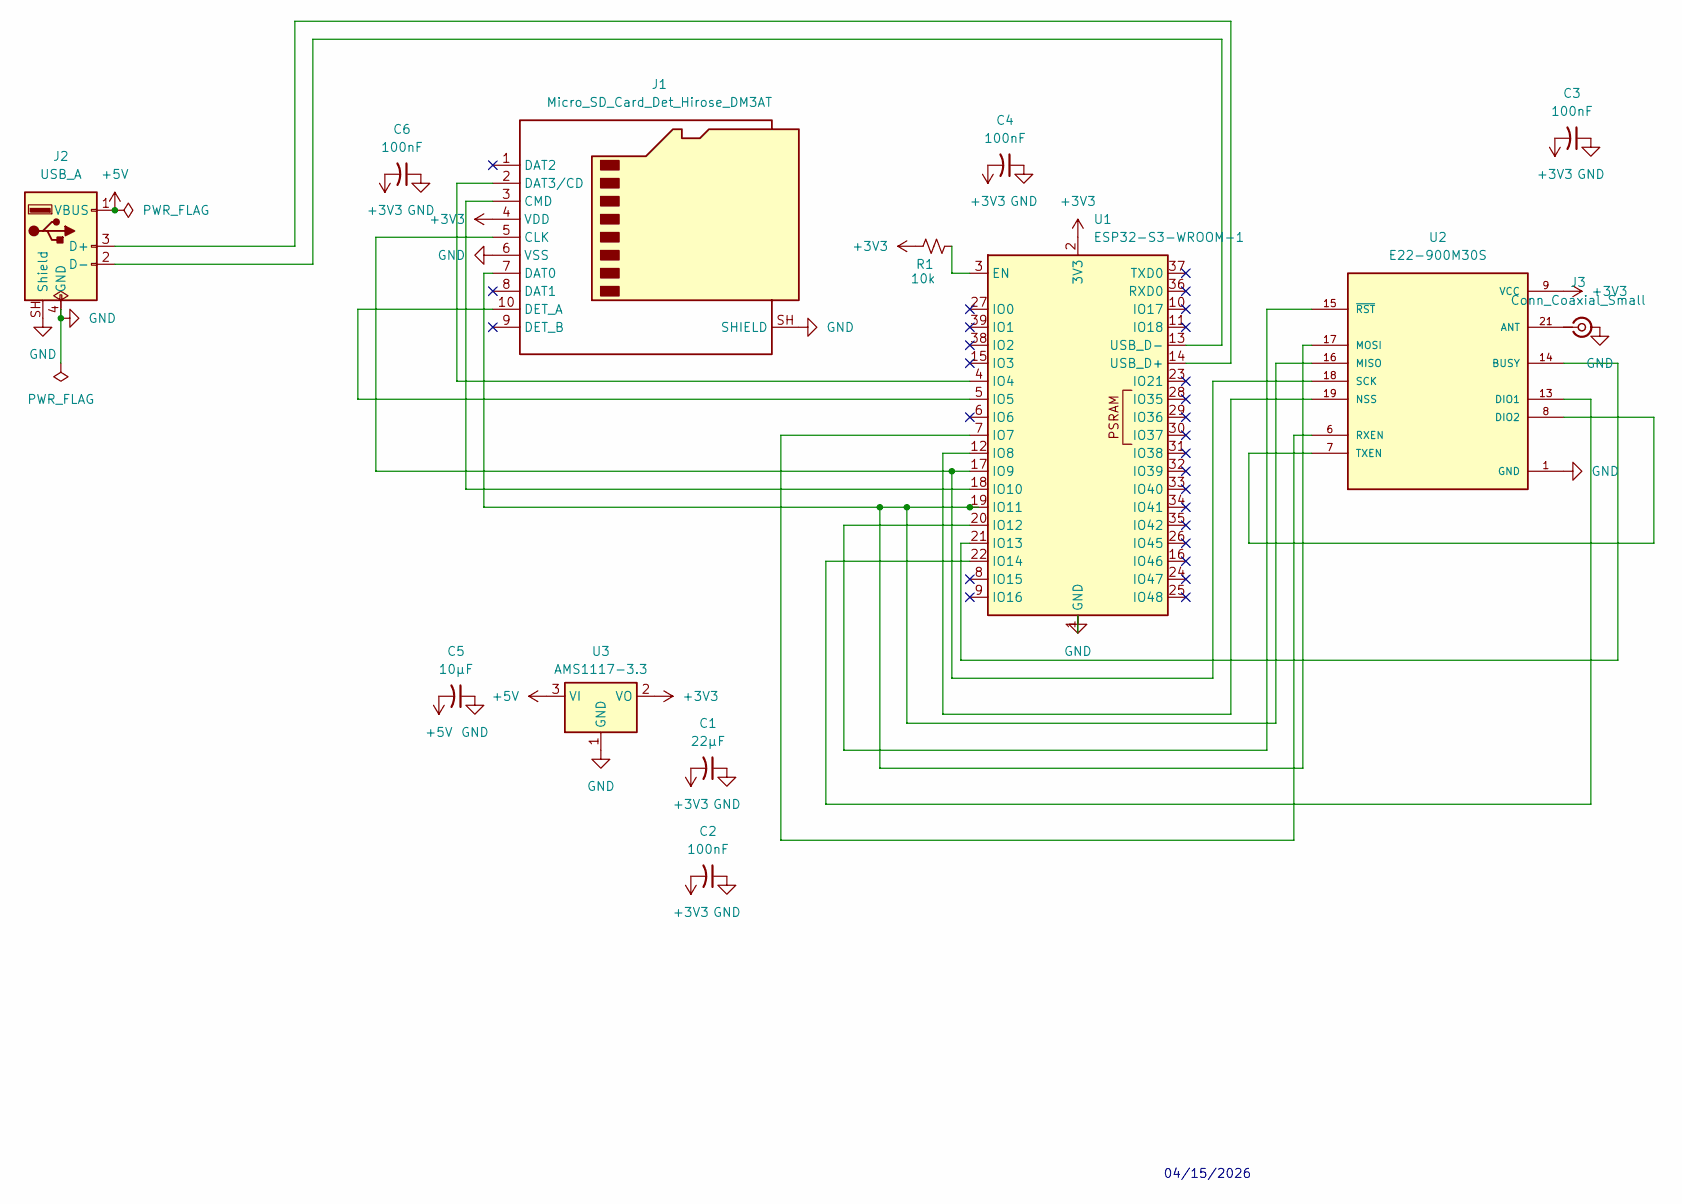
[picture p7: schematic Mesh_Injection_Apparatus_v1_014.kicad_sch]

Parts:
C1: 22μF; C_0805_2012Metric
C2, C3, C4, C6: 100nF; C_0805_2012Metric
C5: 10μF; C_0805_2012Metric
J1: Micro_SD_Card_Det_Hirose_DM3AT
J2: USB_A; USB3_A_Plug_Wuerth_692112030100_Horizontal
J3: Conn_Coaxial_Small; U.FL_Hirose_U.FL-R-SMT-1_Vertical
R1: 10k; R_0805_2012Metric_Pad1.20x1.40mm_HandSolder
U1: ESP32-S3-WROOM-1
U2: E22-900M30S; XCVR_E22-900M30S; PARTREV 1.2
U3: AMS1117-3.3; SOT-223-3_TabPin2

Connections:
+3V3: C1.2, C2.2, C3.2, C4.2, C6.2, J1.4 (VDD), R1.1, U1.2 (3V3), U2.9 (VCC), U2.10 (VCC), U3.2 (VO)
+5V: C5.2, J2.1 (VBUS), U3.3 (VI)
GND: C1.1, C2.1, C3.1, C4.1, C5.1, C6.1, J1.6 (VSS), J1.SH (SHIELD), J2.4 (GND), J2.SH (Shield), J3.2 (Ext), U1.1 (GND), U1.40 (GND), U1.41 (GND), U2.1 (GND), U2.2 (GND), U2.3 (GND), U2.4 (GND), U2.5 (GND), U2.11 (GND), U2.12 (GND), U2.20 (GND), U2.22 (GND), U3.1 (GND)
unnamed: J1.5 (CLK), U1.17 (IO9), U2.18 (SCK)
unnamed: J1.3 (CMD), U1.18 (IO10)
unnamed: J1.7 (DAT0), U1.19 (IO11), U2.16 (MISO), U2.17 (MOSI)
unnamed: J1.2 (DAT3/CD), U1.4 (IO4)
unnamed: J1.10 (DET_A), U1.5 (IO5)
unnamed: J2.3 (D+), U1.14 (USB_D+)
unnamed: J2.2 (D-), U1.13 (USB_D-)
unnamed: J3.1 (In), U2.21 (ANT)
unnamed: R1.2, U1.3 (EN)
unnamed: U1.7 (IO7), U2.6 (RXEN)
unnamed: U1.12 (IO8), U2.19 (NSS)
unnamed: U1.20 (IO12), U2.15 (~RST)
unnamed: U1.21 (IO13), U2.14 (BUSY)
unnamed: U1.22 (IO14), U2.13 (DIO1)
unnamed: U2.7 (TXEN), U2.8 (DIO2)

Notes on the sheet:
04/15/2026

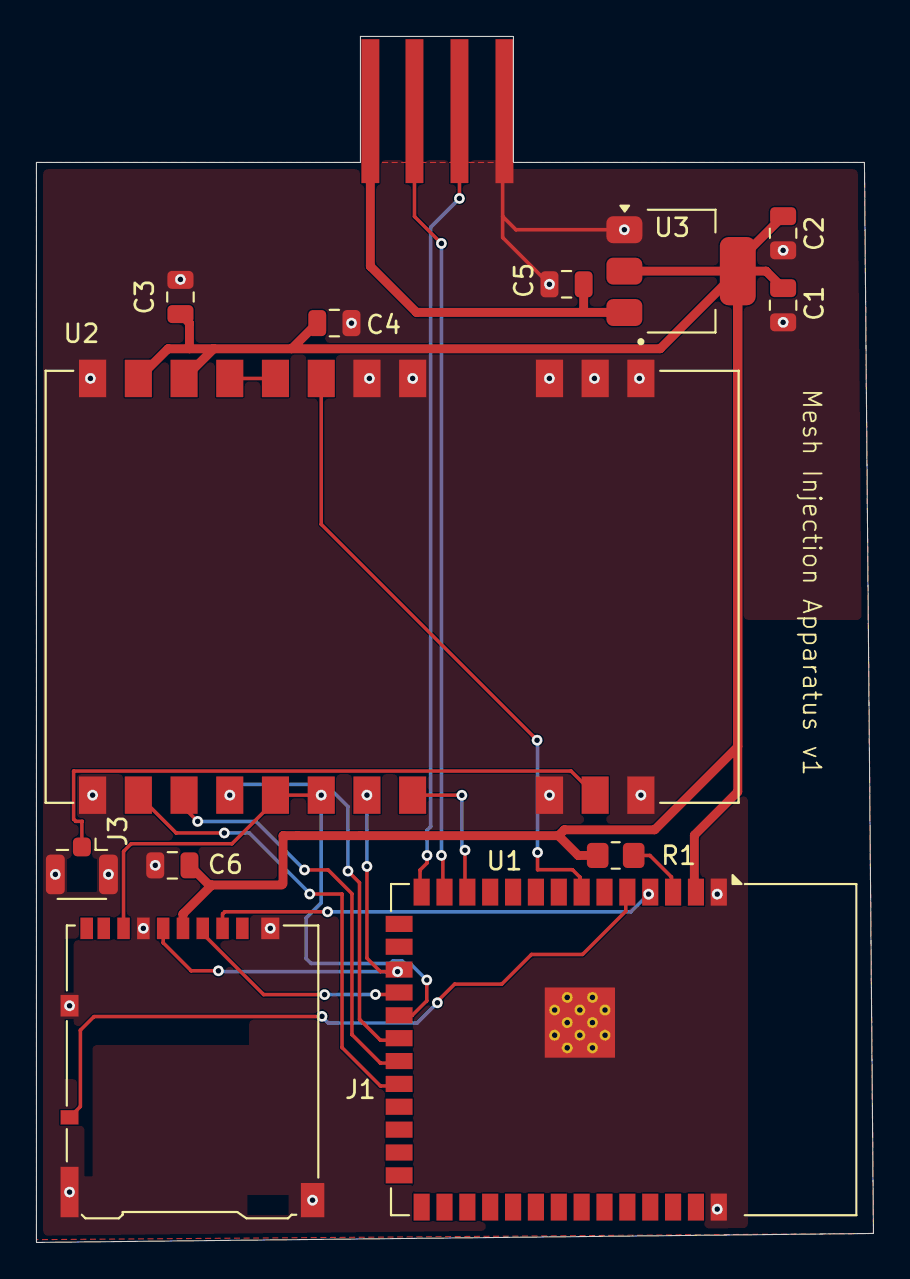
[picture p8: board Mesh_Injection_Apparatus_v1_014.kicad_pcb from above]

Board: 2 copper layers, 46.5 x 67.0 mm, 12 parts (0 on the bottom side), 16 nets.

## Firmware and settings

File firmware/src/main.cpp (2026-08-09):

#include <Arduino.h>
#include <Preferences.h> //for persistent storage
#include "Logger.h"
#include "HID.h"
#include "Radio.h"
#include "Crypto.h"
#include "StatusLED.h"
#include "SerialApi.h" 
#include "WebApi.h"
#include "WifiConfig.h"
#include "PacketParser.h" 


// PIN DEFINITIONS — board specific
#ifdef LILYGO_T3S3
    #define LED 37
    // no VEXT on T3-S3
#elif defined(MIA_PCB)
    // no LED, no VEXT on MIA PCB v1
#else
    // Heltec V3
    #define LED 35
    #define VEXT_ENABLE 36
#endif

//initial declaration for retransmitted packet variables 
uint32_t lastExecutedPacketId = 0;
uint32_t lastExecutedSource = 0;

//AES Key (default = 0x01, aka AQ== in B64)
const uint8_t defaultKey[16] = {
    0xd4, 0xf1, 0xbb, 0x3a, 0x20, 0x29, 0x07, 0x59,
    0xf0, 0xbc, 0xff, 0xab, 0xcf, 0x4e, 0x69, 0x01,
};
        
Radio radio; //allocates memory for Radio object
SerialApi serialApi; //same thing for SerialAPI
WebApi webApi; //same, for WebAPI
WifiConfig wifiConfig; //you guessed it
Crypto crypto;


void setup() {
    Serial.begin(115200);
    delay(3000);  // give CDC time to connect
    Serial.println("SETUP START");
#ifdef VEXT_ENABLE
    pinMode(VEXT_ENABLE, OUTPUT);
    digitalWrite(VEXT_ENABLE, LOW);
#endif

#ifdef LED
    StatusLED::begin(LED);
#endif

    Serial.begin(115200);
    delay(2000); //wait for serial monitor init

    Logger::rawln("===============================");
    Logger::rawln("  M.esh I.njection A.pparatus ");
    Logger::rawln("===============================");
    Logger::info("Booting...");

    Logger::rawln("About to init radio...");
    bool radioOk = radio.begin();
    Logger::rawln(radioOk ? "Radio OK" : "Radio FAILED");
    if (!radioOk){
        Logger::rawln("Radio init failed - continuing anyway for diagnostics");
        // don't halt - keep going so serial stays alive
    }
    
    //loads wifi config
    wifiConfig.begin(); 

    //serial API start
    serialApi.begin(&radio, &wifiConfig, &webApi, &crypto);
    webApi.begin(&radio, &crypto, &wifiConfig, wifiConfig.ssid.c_str(), wifiConfig.password.c_str());
    Logger::rawln("Serial API loaded.");

    if (wifiConfig.apEnabled) {
        webApi.begin(&radio, &crypto, &wifiConfig, wifiConfig.ssid.c_str(), wifiConfig.password.c_str());
        Logger::rawln("Web API ready.");
    } else {
        Logger::rawln("Web API disabled (send set_wifi over serial to enable).");
    }



    //USB HID Init
    Logger::raw("Initializing USB HID...");
    HID::begin();
    Logger::rawln("OK!");

    crypto.begin(defaultKey, 16);
}

void loop(){
    serialApi.handle(); //processes serial commands each iteration
    if(radio.packetAvailable()){
        //buffer for recieved bytes
        uint8_t buffer[255];
        size_t len;
        int state = radio.receivePacket(buffer, sizeof(buffer), len); //read packet from radio
        
        if (state == RADIOLIB_ERR_NONE) {
            Logger::rawln("\n----Packet Recieved---");
            Logger::raw("Length: ");
            Logger::raw((int)len);
            Logger::rawln(" bytes");

            Logger::raw("\n RSSI: ");
            Logger::raw(radio.getRSSI());
            Logger::rawln(" dBm");
            Logger::raw("\n SNR: ");
            Logger::raw(radio.getSNR());
            Logger::rawln(" dB");

            //print raw hex
            Logger::raw("Hex: ");
            for (size_t i = 0; i < len; i++){
                Logger::hexByte(buffer[i]);
            }
            Logger::rawln();

            //header parsing functionality handled with PacketParser
            PacketHeader header = PacketParser::parseHeader(buffer);
            Logger::infof("From: %08X To: %08X ID: %08X Flags: %02X Ch: %02X",
                header.source, header.dest, header.packetId, header.flags, header.channel);
            
            //decrypt payload, added bounds checking
            size_t payloadlen = len - 16;
            if (payloadlen > 0 && payloadlen < 200){
                uint8_t decrypted[200];
                crypto.decrypt(&buffer[16], payloadlen, header.packetId, header.source, decrypted);
                Logger::raw("Encrypted: ");
                for (size_t i = 0; i < payloadlen && i < 16; i++) {
                    Logger::hexByte(buffer[16+i]);
                }
                Logger::rawln();

                //print first 16 bytes of plaintext, in hex (still protobuf encoded)    
                Logger::raw("Decrypted: ");
                for (int i = 0; i < payloadlen; i++) {
                    Logger::hexByte(decrypted[i]);
                }
                Logger::rawln();
            
                //text extraction in Packet Parser
                char textBuffer[200];
                uint8_t textLen;
                if (PacketParser::extractTextMessage(decrypted, payloadlen, textBuffer, sizeof(textBuffer), &textLen)){
                    Logger::rawln("Text message detected (header 0x08 0x01)");
                    Logger::raw("Text length = ");
                    Logger::raw((int)textLen);
                    Logger::rawln(".");
                    Logger::raw("<Text:> ");
                    Logger::rawln(textBuffer);

                    //check for "!mia:" prefix
                    if (strncmp(textBuffer, "!mia:", 5) == 0){
                        if (header.packetId == lastExecutedPacketId && header.source == lastExecutedSource){
                            Logger::info("[MIA] Duplicate/retransmitted packet - skipping");
                        } else {
                            lastExecutedPacketId = header.packetId;
                            lastExecutedSource = header.source;
                            Logger::info("[MIA] Command Detected!");
                            //get pointer to command 
                            char* command = textBuffer + 5;
                            //handle leading whitespace
                            while (*command == ' ') command++;
                            HID::executeCommands(command);
                        }
                    }    
                }
            }  
        }
        StatusLED::blinkReceived();
        radio.startReceive();
    }
         
    static unsigned long lastRSSI = 0;
    if (millis() - lastRSSI > 2000){
        lastRSSI = millis();
        Logger::raw("RF RSSI: ");
        Logger::raw(radio.getRSSI());
        Logger::rawln(" dBm");
    }
    static unsigned long lastIrq = 0;
    if (millis() - lastIrq > 500) {
        lastIrq = millis();
        uint16_t irq = radio.getIrqFlags();
        if (irq != 0) {
            Logger::raw("[IRQ] flags: 0x");
            char irqBuf[8];
            sniprintf(irqBuf, sizeof(irqBuf), "%X", irq);
            Logger::raw(irqBuf);
            Logger::rawln();
        }
    }
}

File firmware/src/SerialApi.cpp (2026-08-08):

#include "SerialApi.h"
#include <ArduinoJson.h>
#include "mbedtls/base64.h"
#include "Crypto.h"

void SerialApi::begin(Radio* radio, WifiConfig* wifi, WebApi* webApi, Crypto* crypto) {
    radioRef = radio;
    wifiRef = wifi;
    webApiRef = webApi;
    cryptoRef = crypto;
}

void SerialApi::handle() {
    while (Serial.available()) {
        char c = Serial.read();

        if (c == '\n') {
            inputBuffer.trim();
            if (inputBuffer.length() > 0) {
                processCommand(inputBuffer);
            }
            inputBuffer = "";
        } else if (c != '\r') {
            inputBuffer += c;
        }
    }
}

void SerialApi::processCommand(const String& line) {
    JsonDocument doc;
    DeserializationError err = deserializeJson(doc, line);

    if (err) {
        Serial.println("{\"error\":\"invalid json\"}");
        return;
    }

    const char* cmd = doc["cmd"] | "";

    if (strcmp(cmd, "get_config") == 0) {
        JsonDocument resp;
        resp["frequency"] = radioRef->getFrequency();
        resp["bandwidth"] = radioRef->getBandwidth();
        resp["spreadFactor"] = radioRef->getSpreadFactor();
        resp["codingRate"] = radioRef->getCodingRate();
        resp["power"] = radioRef->getPower();

        serializeJson(resp, Serial);
        Serial.println();
    }
    
    else if (strcmp(cmd, "set_config") == 0) {
    bool ok = true;

    if (doc["spreadFactor"].is<int>())
        ok &= radioRef->setSpreadFactor(doc["spreadFactor"]);
    if (doc["power"].is<int>())
        ok &= radioRef->setPower(doc["power"]);
    if (doc["frequency"].is<float>())
        ok &= radioRef->setFrequency(doc["frequency"]);
    if (doc["bandwidth"].is<float>())
        ok &= radioRef->setBandwidth(doc["bandwidth"]);
    if (doc["codingRate"].is<int>())
        ok &= radioRef->setCodingRate(doc["codingRate"]);

    Serial.println(ok ? "{\"status\":\"ok\"}" : "{\"status\":\"error\"}");
    }

    else if (strcmp(cmd, "get_wifi") == 0) {
    JsonDocument resp;
    resp["enabled"] = wifiRef->apEnabled;
    resp["ssid"] = wifiRef->ssid;
    // password intentionally omitted from get_wifi to protect PSK
    serializeJson(resp, Serial);
    Serial.println();
    }
    else if (strcmp(cmd, "set_wifi") == 0) {
        if (doc["enabled"].is<bool>())
            wifiRef->setEnabled(doc["enabled"]);
        if (doc["ssid"].is<const char*>())
            wifiRef->setSsid(doc["ssid"].as<String>());
        if (doc["password"].is<const char*>())
            wifiRef->setPassword(doc["password"].as<String>());
    
        Serial.println("{\"status\":\"ok\"}");
    }
    else if (strcmp(cmd, "get_psk") == 0) {
        uint8_t key[32];
        size_t keyLen;
        cryptoRef->getKey(key, &keyLen);
        
        unsigned char b64[64];
        size_t b64Len;
        mbedtls_base64_encode(b64, sizeof(b64), &b64Len, key, keyLen);
        
        JsonDocument resp;
        resp["psk"] = String((char*)b64).substring(0, b64Len);
        serializeJson(resp, Serial);
        Serial.println();
    }
    else if (strcmp(cmd, "set_psk") == 0) {
        if (doc["psk"].is<const char*>()) {
            String psk = doc["psk"].as<String>();
            unsigned char decoded[32];
            size_t decodedLen;
            int rc = mbedtls_base64_decode(decoded, sizeof(decoded), &decodedLen,
                                            (const unsigned char*)psk.c_str(), psk.length());
            if (rc != 0 || (decodedLen != 16 && decodedLen != 32)) {
            Serial.println("{\"error\":\"psk must decode to 16 or 32 bytes\"}");
        } else {
            cryptoRef->setKey(decoded, decodedLen);
            Serial.println("{\"status\":\"ok\"}");
        }

        } else {
            Serial.println("{\"error\":\"missing psk field\"}");
        }
    }
    else if (strcmp(cmd, "save_defaults") == 0) {
    // save current active values into the "defaults" namespace
    Preferences defaults;
    defaults.begin("defaults", false);

    // radio
    defaults.putFloat("freq", radioRef->getFrequency());
    defaults.putFloat("bw", radioRef->getBandwidth());
    defaults.putUChar("sf", radioRef->getSpreadFactor());
    defaults.putUChar("cr", radioRef->getCodingRate());
    defaults.putChar("power", radioRef->getPower());

    // crypto
    uint8_t key[32];
    size_t keyLen;
    cryptoRef->getKey(key, &keyLen);
    defaults.putBytes("key", key, keyLen);
    defaults.putUChar("keylen", keyLen);

    // wifi
    defaults.putBool("ap", wifiRef->apEnabled);
    defaults.putString("ssid", wifiRef->ssid);
    defaults.putString("pass", wifiRef->password);

    defaults.end();
    Serial.println("{\"status\":\"ok\",\"msg\":\"current config saved as defaults\"}");
}
else if (strcmp(cmd, "reset_defaults") == 0) {
    Preferences defaults;
    defaults.begin("defaults", true); // read-only
    bool hasSaved = defaults.getBytesLength("key") > 0;
    defaults.end();

    if (hasSaved) {
        // load user-saved defaults back into active namespaces
        Preferences d;
        d.begin("defaults", true);

        Preferences radio;
        radio.begin("radio", false);
        radio.putFloat("freq", d.getFloat("freq", LORA_FREQ));
        radio.putFloat("bw", d.getFloat("bw", LORA_BAND));
        radio.putUChar("sf", d.getUChar("sf", LORA_SF));
        radio.putUChar("cr", d.getUChar("cr", LORA_CR));
        radio.putChar("power", d.getChar("power", LORA_POWER));
        radio.end();

        Preferences crypto;
        crypto.begin("crypto", false);
        uint8_t key[32];
        size_t keyLen = d.getBytes("key", key, 32);
        crypto.putBytes("key", key, keyLen);
        crypto.end();

        Preferences wifi;
        wifi.begin("wifi", false);
        wifi.putBool("enabled", d.getBool("ap", false));
        wifi.putString("ssid", d.getString("ssid", "Mesh Injection Apparatus"));
        wifi.putString("password", d.getString("pass", "Mesh-Inject-7f3K9pQ2"));
        wifi.end();

        d.end();
        Serial.println("{\"status\":\"ok\",\"msg\":\"defaults restored, reboot to apply\"}");
    } else {
        // no user defaults saved — wipe to compiled-in values
        Preferences radio; radio.begin("radio", false); radio.clear(); radio.end();
        Preferences crypto; crypto.begin("crypto", false); crypto.clear(); crypto.end();
        Preferences wifi; wifi.begin("wifi", false); wifi.clear(); wifi.end();
        Serial.println("{\"status\":\"ok\",\"msg\":\"factory reset, reboot to apply\"}");
    }
}
else {
    Serial.println("{\"error\":\"unknown cmd\"}");
}
}

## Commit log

2026-07-15 Working firmware before architecture refactor
    [.kicad_sch.kicad_sch, Mesh Injection Apparatus v1.13.kicad_sch, Mesh Injection Apparatus v1.14.kicad_sch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]
2026-07-15 chore: stop tracking website build artifacts and KiCad backup/lock files
2026-07-15 chore: remove KiCad restore-backup snapshots and session lock file
    [.kicad_sch.kicad_sch, Mesh Injection Apparatus v1.13.kicad_sch, Mesh Injection Apparatus v1.14.kicad_sch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]
2026-07-15 chore: scaffold hardware/ directory structure (both boards unmanufactured, kept under experimental/)
    [Mesh_Injection_Apparatus_v1_014-B_Cu.gbr, Mesh_Injection_Apparatus_v1_014-B_Mask.gbr, Mesh_Injection_Apparatus_v1_014-B_Paste.gbr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]
2026-07-15 chore(hardware): drop malformed local gerber zip exports; will re-source from JLCPCB order or re-plot as needed
2026-07-15 refactor(hardware): move mia-v1-015 PCB source, BOM, gerbers, and pick-and-place into hardware/
    [Mesh_Injection_Apparatus_v1_015-B_Cu.gbr, Mesh_Injection_Apparatus_v1_015-B_Mask.gbr, Mesh_Injection_Apparatus_v1_015-B_Paste.gbr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]
2026-07-15 refactor(hardware): move mia-v1-014 PCB source, BOM, and DRC report into hardware/
    [Mesh_Injection_Apparatus_v1_014.kicad_pcb, Mesh_Injection_Apparatus_v1_014.kicad_sch, mia-v1-014-bom.csv]
2026-07-15 refactor(hardware): resolve remaining mia-v1-014 files — dedupe pick-and-place, archive old schematic snapshots
    [Mesh Injection Apparatus v1.13.kicad_sch, Mesh Injection Apparatus v1.14.kicad_sch, orphan-sheet.kicad_sch]
2026-07-15 refactor(hardware): move custom footprint library into hardware/footprints
2026-07-15 fix(hardware): correct footprint library path after relocating myfootprints.pretty; remove duplicate lib entry
2026-07-15 chore: add .gitignore covering KiCad backups, build artifacts, editor cruft
2026-07-16 firmware(feature): added Version.h and Logger class (verified compiles, but not yet wired into main.cpp)
2026-07-17 Firmware (feature): wired Logger into main.cpp, all serial calls now routed through Logger class
2026-07-18 refactor(firmware): extract HID class from main.cpp
    - Move executecommand()/executecommands() into HID::executeCommand()/executeCommands()
    - Move USB.begin()/Keyboard.begin() into HID::begin()
    - Keyboard object now static/private inside HID.cpp, no longer a main.cpp global
    - Fix stuck-modifier bug and mesh dedup logic (see CHANGELOG)
    - No functional change beyond documented fixes; confirmed working on hardware
    [Logger.cpp, main.cpp]
2026-07-20 Refractor: extracted Radio class (SPI/LoRa init, RX handling, status getters)
2026-08-03 Add WebApi: HTTP-based radio config over ESP32 AP
2026-08-07 Update ARCHITECTURE.md to reflect current module structure
2026-08-07 WebApi: LittleFS dashboard, inject endpoints, PSK/WiFi/board API
    [Mesh_Injection_Apparatus_v1_014.kicad_pcb]
